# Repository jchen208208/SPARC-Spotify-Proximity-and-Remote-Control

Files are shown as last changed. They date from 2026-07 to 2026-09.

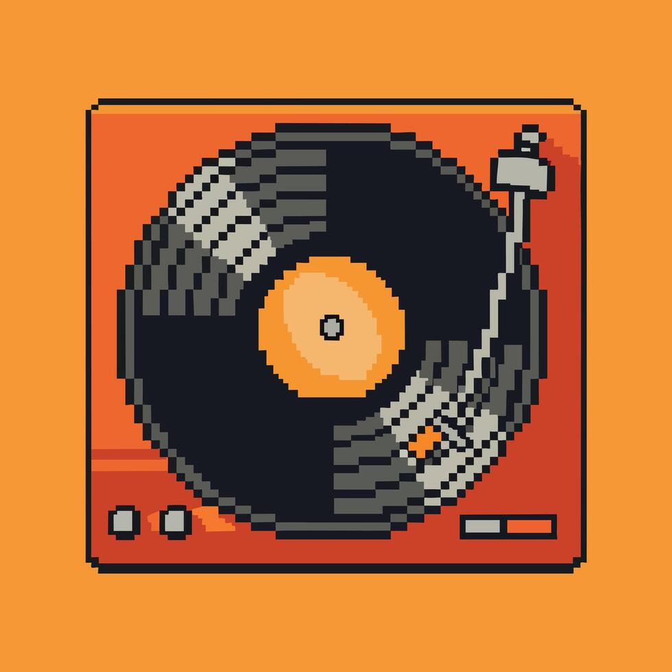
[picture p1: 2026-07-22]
SPARC_assets/record_image.jpg

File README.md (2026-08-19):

# 🎵 SPARC

SPARC

**S**potify **P**roximity **a**nd **R**emote **C**ontrol — a desk-mounted gesture controller.
Wave your hand over it to skip tracks, change volume, or pause. No touchscreen, no buttons,
no phone.

Built for situations where looking at a screen is inconvenient or unsafe — adjusting music
while driving, mainly.

---

## How it works

SPARC pairs to your phone or laptop as a **Bluetooth media remote** — the same class of
device as the play/pause button on a pair of headphones.

It does not talk to Spotify. It sends standard HID media-key presses to the operating
system, which routes them to whatever app is currently playing. That means:

- **No app to install** — pair it in Bluetooth settings and it works
- **No Spotify account, login, or Premium subscription**
- Works on **iOS, Android, macOS, Windows, Linux**
- Works with **any** media app — Spotify, Apple Music, YouTube, podcasts

It also works with the screen off and the phone in your pocket, for the same reason your
headphone buttons do.

---

## Gestures

Two zones above the sensor:

| Zone | Range | Controls |
|---|---|---|
| 1 | 2–15 cm | Tracks |
| 2 | 15–30 cm | Volume |

| Gesture | Zone 1 | Zone 2 |
|---|---|---|
| Single pass | ⏭ Next track | 🔊 Volume up |
| Double pass (within 0.8s) | ⏮ Previous track | 🔉 Volume down |
| Hold (0.3s) | ⏯ Play/pause | ⏹ Stop the volume ramp |

Volume ramps continuously once started. Hold your hand still to stop it.

---

## Hardware

| Component | Notes |
|---|---|
| ESP32 (WROOM-32) | Built-in Bluetooth — no separate radio module |
| VL53L0X | Time-of-flight distance sensor, I²C on SDA 21 / SCL 22 |
| 8× WS2812B | Volume bar, data on GPIO 18 |
| LED | Play/pause flash, GPIO 4 |

Runs off a power bank.

---

## Flashing

Requires the ESP32 board core, plus the `NimBLE-Arduino`, `Adafruit_VL53L0X` and `FastLED`
libraries.

```bash
arduino-cli compile --fqbn esp32:esp32:esp32 --port /dev/cu.usbserial-0001 --upload sketch_esp_hid
```

Then pair "SPARC" from your device's Bluetooth settings. That's the whole setup.

> A BLE device stops advertising while connected. To pair it to something else, disconnect
> — or **forget** it — on the current device first, or it won't be discoverable.

---

## Repo layout

| Path | |
|---|---|
| `sketch_esp_hid/` | **The product.** BLE HID firmware |
| `sketch_esp/` | Older firmware that talks to the desktop app over Bluetooth Serial |
| `Main.py`, `ui.py`, `core.py` | Desktop app — demo only, see below |
| `Wired_version/`, `Uno_version/`, `sketch_nano/` | Earlier hardware revisions, kept for reference |

**The desktop app is a demo artifact, not part of the product.** It shows album art, a queue
wheel and gesture animations, but it needs the Spotify Web API — which is exactly the
limitation the HID firmware exists to escape. It only works with `sketch_esp/` firmware
flashed; the two builds are mutually exclusive.

---

## Project timeline

What we tried, what broke, and what we changed.

| Stage | Problem | Fix |
|---|---|---|
| **Proximity volume** | Mapping hand *distance* to volume was buggy and misread hand position constantly. Roughly a full day lost to it. | Scrapped continuous tracking for discrete swipes — single pass, double pass, hold. |
| **USB tether** | The board had to stay plugged into the laptop, so it wasn't really a remote. | Went wireless. Tried WiFi first, settled on Bluetooth with an HC-05. |
| **HC-05 on macOS** | Pairing and holding a stable serial connection took a lot of troubleshooting. | Worked through the port/pairing issues, then moved to an ESP32 — its built-in radio removed the separate module entirely. |
| **Terminal window** | The packaged executable still opened a terminal on launch. Not a product. | Built a proper macOS `.app` with a status UI and gesture animations. |
| **Spotify API cap** ⚠️ | Spotify cut Development Mode to **5 users** in Feb 2026 and required Premium. Extended quota has been organisations-only since May 2025 — no application path for us. **Hard ceiling on the entire product.** | Stopped using the API. Became a **BLE HID device** instead, so the OS routes the commands. Removed the user cap, the Premium requirement, and the app install in one change — and made iPhone possible for the first time, since iOS never supported the old Bluetooth Serial transport. |

### Along the way

- **Leaked credentials.** Early commits contained Spotify tokens. Moved to `.env`, gitignored, purged from history.
- **Sensor took the whole board down.** On a cold power-up the VL53L0X is still booting when `begin()` runs. Failing silently wedged `setup()`, so Bluetooth never came up and the board looked dead. Now it retries five times and carries on regardless.
- **The on-screen keyboard trap.** Off-the-shelf ESP32 HID libraries declare themselves as keyboards, which makes iOS hide the on-screen keyboard system-wide — you couldn't type in any app while SPARC was connected. Fixed by hand-writing a report descriptor that declares media keys *only*.

---

## What's next

- Solder onto perfboard, ditch the breadboard
- Build a case
- A pairing gesture, so switching between devices doesn't mean digging through Bluetooth settings

---

## License

MIT

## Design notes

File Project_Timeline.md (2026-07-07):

# SPARC — Project Timeline

**SPARC (Spotify Proximity and Remote Control)** is a desk-mounted gesture controller that lets you control Spotify hands-free using an Arduino, an ultrasonic distance sensor, and a Python backend connected to the Spotify Web API.

This document tracks the project from the original idea to the current state: what we built at each stage, the problems we ran into, and how we solved them.

---

## Phase 0 — The Idea (early June 2026)

The idea started about a month before the repo existed: control Spotify with hand gestures in the air — no touchscreen, no buttons, no phone. The long-term vision was a product for situations where looking at a screen is inconvenient or unsafe, like adjusting music while driving.

The idea was pitched to two friends, and the three of us formed the team.

---

## Phase 1 — Software Foundation: Python + Spotify API (June 16–17)

**Commits:** `Initial commit` → `toggle playback`

- Created the GitHub repo, README, and MIT license (June 16).
- Set up the Spotify Developer account, created the app project, and connected to the Spotify Web API using **Spotipy**.
- Wrote the first draft of `Main.py` — the backend script that listens for gesture commands and translates them into Spotify API calls (play/pause, next/previous track, volume).
- Wrote the first Arduino firmware draft (`sketch.ino`) for reading the HC-SR04 ultrasonic sensor.

**Issue — leaked credentials:** Early commits included the Spotify cache/token and hardcoded credentials. We moved all private data (client ID, client secret) into a `.env` file, added it to `.gitignore`, and purged the cached tokens from version control (`used a .env folder for private data`, `security fix`, `Delete .spotify_cache`).

---

## Phase 2 — Hardware Build + First Gesture System (June 17–18)

**Commits:** `Create sketch.ino` → `serial signal rework`

- Built the circuit on a breadboard: Arduino Uno + HC-SR04 ultrasonic sensor + jumper wires.
- Programmed the Arduino to classify hand motions and send gesture labels as plain text over USB Serial to the Python script.

**Original design — proximity-based volume:** Hold your hand in a zone, then move it *closer* to the sensor to decrease volume and *farther away* to increase it.

**Issue — the proximity approach didn't work:** The zone/distance-tracking system was buggy and unreliable — it kept misreading hand position and never behaved the way we wanted. Roughly a full day of commits (`pauses fix`, `pause fix again`, `killed V_start`, multiple `sketch.ino` rewrites) went into trying to stabilize it.

**Solution — pivot to swipe gestures.** We scrapped continuous distance tracking and switched to discrete swipe motions:

- **One swipe** → volume up / next track
- **Two swipes** → volume down / previous track
- **Hold** → stop volume change, or toggle play/pause

The commit `new gesture system that ACTUALLY WORKS` (June 18) marks the turning point. After reprogramming the Arduino and testing, everything worked great. We also added false-trigger filtering (distance cap, consecutive-reading confirmation, gesture cooldown) and tuned the volume step rate (`step: 7%, interval: 0.1s`).

---

## Phase 3 — Polish: Sound Effects + Volume LEDs (June 18)

**Commits:** `mp3 files` → `LED FINAL PULL FROM HERE IF EXPLOSION`

- Added **connected / disconnected sound effects** so the user gets audio feedback when the Python script links up with (or loses) the Arduino and Spotify.
- Added **volume indicator LEDs** to the breadboard that light up to show the current volume percentage inside the Spotify app. Got them fully working the same day.

---

## Phase 4 — Going Wireless (June 18–22)

**Commits:** `WiFi IMPLEMENTATION` → `BLUETOOTH WORKS!`

Up to this point, the Arduino had to be plugged into the laptop by USB cable for serial communication — not exactly a remote control.

- First explored a WiFi approach (`WiFi IMPLEMENTATION`).
- Preserved the working USB version in a `Wired_version/` folder as a stable fallback before making wireless changes.
- Settled on Bluetooth using an **HC-05 module**.

**Issue — Mac ↔ HC-05 connection problems:** Getting macOS to reliably pair and hold a serial connection with the HC-05 took a lot of troubleshooting (`BLUETOOTH WORKS!` followed immediately by `fixing bluetooth issue`). After working through the pairing/port issues, the Bluetooth link became stable.

**Result:** The device now runs fully wireless — the Arduino is powered by a power bank and communicates with the laptop over Bluetooth. We also fixed the LEDs to turn off completely when the program disconnects.

---

## Phase 5 — From Script to App (July 5)

**Commits:** `executable file` → `added gesture corresponding animations in the app ui`

The next barrier to a customer-ready product: you had to open an IDE and manually run the Python script.

1. **First attempt — standalone executable:** Packaged `Main.py` into an executable. Problem: it still opened a terminal window when launched, which isn't a good user experience.
2. **Solution — a proper macOS `.app`:** Built a real application with a UI that shows:
   - Whether the **sensor (Arduino)** is connected
   - Whether **Spotify** is connected
   - When both are connected, a "playing" state with **animations for each gesture action**
3. Added the SPARC logo to the UI and as the dock icon, and fixed remaining security issues.

This is the current state of the project: a wireless, power-bank-powered gesture sensor controlled through a double-clickable desktop app.

---

## Current Challenges

### Scaling / Spotify API limits
Each Spotify Developer app in development mode only supports a small number of allowlisted users (~5 active users). Spinning up more developer accounts per batch of users is not maintainable. Moving past this requires applying for **extended quota access**, but Spotify grants that to established companies with significant monthly active users — which isn't feasible for us right now. This makes the project hard to scale into a full startup at the current moment.

---

## What's Next

- **Ditch the breadboard:** Move to an **Arduino Nano** soldered onto a **perfboard** with all wires and resistors, making the whole device far more compact.
- **Build a displayable case:** Enclose the electronics so it looks like an actual product instead of a sensor attached to wires and a microcontroller.

---

## Timeline at a Glance

| Date | Milestone |
|---|---|
| ~Early June 2026 | Idea conceived and pitched; team of 3 formed |
| June 16 | Repo created; README + MIT license |
| June 17 | Spotify Developer setup, API connected, first `Main.py` and Arduino sketch |
| June 17–18 | Circuit built; proximity-based volume control attempted and abandoned |
| June 18 | Swipe-gesture system working; sound effects + volume LEDs added |
| June 18–19 | Wired version stabilized; wireless work begins |
| June 22 | Bluetooth (HC-05) working after Mac pairing troubleshooting |
| July 5 | Standalone executable → full `.app` with status UI, logo, and gesture animations |
| Next | Solder onto perfboard with Arduino Nano; build product case |

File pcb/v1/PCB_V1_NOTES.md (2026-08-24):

# PCB v1 — known issues and bring-up notes

Findings from bringing up the first SPARC PCB on **2026-08-23**. This board carries a bare
`ESP32-WROOM-32` module instead of a devboard, which is where most of the trouble came from.

**TL;DR:** the board works, but the Reset and BOOT buttons are wired across the power rail
instead of to their signal pins, so they do nothing except short 3.3V to ground. Flashing
requires a jumper wire until v2. See [Flashing v1](#flashing-v1-the-jumper-workaround).

---

## What happened

A teammate flashed this board successfully twice on 2026-08-22, then it stopped working
entirely and never flashed again — on his machine or a different one, with or without
reinstalling the USB driver. The same CP2102 adapter flashed a devboard on a breadboard
without issue, which ruled out the adapter, the cable, and the host.

The cause was in the schematic, not the computers.

### The buttons short the power rail

`SW4` (Reset) and `SW5` (BOOT) are each connected **between +3.3V and GND**, rather than
between their signal pin and GND. Tracing the nets:

```
+3.3V ──┬── R4.2   (R4 = 10k, R4.1 → EN)
        └── SW4.2
                      SW4.1 ── GND        ← SW4 closed = +3.3V shorted to GND

+3.3V ──┬── R5.1   (R5 = 10k, R5.2 → IO0)
        └── SW5.2
                      SW5.1 ── GND        ← SW5 closed = +3.3V shorted to GND
```

The pull-ups themselves are correct — `R4` pulls `EN` high, `R5` pulls `IO0` high. The
mistake is that the buttons landed on the **rail side** of each resistor instead of the
**signal side**. Two consequences:

1. Pressing either button collapses the 3.3V rail instead of pulling its pin low.
2. `EN` and `IO0` have **no path to ground at all**, so `GPIO0` can never be held low —
   which makes download mode unreachable by design.

Correct wiring is `EN ── SW4 ── GND` and `IO0 ── SW5 ── GND`.

### Why it worked twice and then never again

Pressing a button browns out the rail. On release the ESP32 does a power-on reset while
`EN` and `IO0` ramp back up through *identical* 10k pull-ups. If `IO0` happens to still be
below its threshold when `EN` crosses its own, the chip latches into download mode by
accident.

That is a genuine race, sensitive to supply ramp rate, cable, temperature and USB port. It
succeeds occasionally and then never again, and no amount of driver reinstalling touches
it. It matched the reported symptom exactly.

> **Do not press Reset or BOOT on a v1 board.** They only short the rail. Use `Switch1` as
> the reset.

### Other v1 problems found

- **`LDO1` (AP2112K-3.3) enable pin floats.** Pin 3 is unconnected, and the part has no
  internal pull-up on `EN` — it must be driven high. The rail happened to come up on
  2026-08-23, but this is an independent source of "works one day, dead the next."
- **No capacitor on `EN`.** The usual 0.1µF to GND for a clean power-on reset is missing.
- **No I2C pull-ups.** `IO16` and `IO17` connect only the ESP32 to the sensor connector.
  It currently works because most VL53L0X breakouts carry their own and the ESP32's
  internal pull-ups are enabled by default, but those are weak (~45kΩ) and fragile.
- **`CP2102.1 (VCC)` is unconnected.** Not a defect — the board is self-powered from the
  TP4056 — but it means the programmer cannot power the board. `Switch1` must be on and
  the TP4056 must have power before flashing.

---

## Flashing v1: the jumper workaround

Since the BOOT button can't pull `GPIO0` low, do it manually. **No soldering required** —
a jumper wire held by hand is enough.

### The two pads

Both are castellations on the **same edge of the ESP32 module** — the edge facing the
CP2102 connector:

| Pad | Signal | Where |
|---|---|---|
| **25** | `IO0` | The **corner** castellation where the bottom row turns and heads up the side, immediately next to pad 24. Sits level with the CP2102 connector's 4th pad, ~5mm away. |
| **38** | `GND` | The far end of that same edge, ~16mm from pad 25. |

> **Counting trap.** This footprint is **14 / 10 / 14**, not the 15 / 8 / 15 shown in most
> online WROOM-32 pinout diagrams. The bottom row is pads 15–24, so **pad 25 is the first
> pin of the side column, not the second.** Getting this wrong costs a lot of failed
> attempts.

Alternative front-side target, ~3mm apart on larger SMD pads: `R5`'s pad facing away from
`R4` (= `IO0`), and `SW5` pad 1 (= `GND`).

### Steps

1. Power the board: TP4056 powered, `Switch1` **on**. The programmer does not power it.
2. Connect the CP2102 to the 4-pin JST header and to the computer. macOS needs **no
   driver** — it has had a built-in CP2102 driver since Big Sur, and installing the Silicon
   Labs one can conflict with it and break things.
3. Hold a jumper wire between **pad 25 and pad 38**.
4. **While still holding it**, flip `Switch1` off, then on. `GPIO0` is sampled only at the
   instant of reset, so the wire must already be in contact — touching it down afterwards
   does nothing.
5. Hold a second longer, then release. Download mode persists until the next reset, so
   there is no rush to run the command.

### Confirming it worked

Watch the ROM banner at **115200 baud** (the app itself runs at 9600):

| Output | Meaning |
|---|---|
| `boot:0x13 (SPI_FAST_FLASH_BOOT)` | Normal boot — `GPIO0` was high, **try again** |
| `boot:0x3 (DOWNLOAD_BOOT(UART0/...))` | **Download mode reached** |

This is much faster feedback than letting `esptool` time out, and it distinguishes "wrong
pad" from "no contact" from "board is dead."

### Flashing

There is **no auto-reset circuit** (DTR/RTS are not wired to the module), so `esptool` must
be told not to reset:

```bash
ESPTOOL=~/Library/Arduino15/packages/esp32/tools/esptool_py/5.3.1/esptool
BUILD=~/Library/Caches/arduino/sketches/<sketch-hash>

$ESPTOOL --port /dev/cu.usbserial-0001 --before no-reset --after no-reset chip-id

$ESPTOOL --port /dev/cu.usbserial-0001 --before no-reset --after no-reset write-flash \
  0x1000  $BUILD/sketch_esp_hid.ino.bootloader.bin \
  0x8000  $BUILD/sketch_esp_hid.ino.partitions.bin \
  0xe000  $BUILD/boot_app0.bin \
  0x10000 $BUILD/sketch_esp_hid.ino.bin
```

Then **remove the jumper** and flip `Switch1` off/on to run the new firmware. Leaving the
wire on just drops it back into download mode.

### Troubleshooting

| Symptom | Cause |
|---|---|
| No `/dev/cu.usbserial*` at all | Adapter unplugged, or a charge-only USB cable |
| `Failed to connect: No serial data received` | Not in download mode — repeat the jumper sequence |
| Nothing on serial at any baud | No 3.3V (floating LDO enable), or TX/RX swapped |
| Boot log missing but board runs | `GPIO15` low at reset suppresses the ROM log by design |

---

## The I2C swap: unresponsive sensor

After remapping the sketch to the PCB pinout, the sensor still reported:

```
VL53L0X NOT FOUND - check wiring (SDA=16, SCL=17, 3V3, GND)
```

### How it was found

The schematic nets read:

```
U2.27(IO16) ── VL53L0X1.3(SDA)
U2.28(IO17) ── VL53L0X1.4(SCL)
```

A brief detour worth recording: `U2.27` and `U2.28` are **pad numbers, not GPIO numbers**.
Pad 27 carries `IO16` and pad 28 carries `IO17`. The giveaway is that **`GPIO28` does not
exist on the ESP32** — its GPIOs are 0–19, 21–23, 25–27 and 32–39.

So per the schematic, `SDA = IO16` and `SCL = IO17`. But on the physical board the two are
**reversed**: `SCL` is on `IO16` and `SDA` is on `IO17`. Either the connector's pin labels
in the schematic are wrong, or the sensor cable is crossed.

I2C is unforgiving about this — a swapped pair produces no bus acknowledgement at all,
which surfaces as `lox.begin()` failing, indistinguishable from an unplugged sensor.

### The fix

Swapping the two constants in the sketch was enough — no rewiring:

```c
#define I2C_SDA 17          // schematic labels these the other way round;
#define I2C_SCL 16          // the board is actually wired SDA=17, SCL=16
```

After reflashing: `VL53L0X ready`, with live distance readings.

---

## Firmware pin mapping

The PCB and the perfboard use completely different pins, so `sketch_esp_hid.ino` selects
between them with a single `#define` at the top. Comment out `BOARD_PCB_V1` to build for
the perfboard.

| Function | PCB v1 | Perfboard |
|---|---|---|
| VL53L0X SDA | `IO17` | `IO21` |
| VL53L0X SCL | `IO16` | `IO22` |
| NeoPixel DIN | `IO15` (via R6) | `IO18` |
| Status LED | `IO27` (via R7) | `IO4` |

`GPIO18`, `GPIO4`, `GPIO21` and `GPIO22` are unconnected on the PCB.

> `GPIO15` is a strapping pin — if it is low at reset the ROM boot log is suppressed. It
> reads high in practice here, so the NeoPixel on that pin has not caused problems, but it
> is worth remembering when a board appears silent.

---

## PCB v2 change list

The four changes to make, in priority order.

### 1. Rewire both buttons — *critical*

Move each button from the rail side of its pull-up to the signal side. This is the change
that turns flashing from a jumper-wire ordeal into pressing two buttons.

```
current (broken):                    v2 (correct):

+3.3V ─┬─ R4 ─ EN                    +3.3V ─ R4 ─┬─ EN
       └─ SW4 ─ GND                               └─ SW4 ─ GND

+3.3V ─┬─ R5 ─ IO0                   +3.3V ─ R5 ─┬─ IO0
       └─ SW5 ─ GND                               └─ SW5 ─ GND
```

- `SW4` (Reset): `EN` ── `SW4` ── `GND`
- `SW5` (BOOT): `IO0` ── `SW5` ── `GND`

### 2. Tie the LDO enable pin high — *critical*

`LDO1` pin 3 (`EN`) is floating. Connect it to `VIN` (pin 1) for always-on. Without this
the 3.3V rail is unreliable and the board may fail to power up at random.

### 3. Add I2C pull-ups

Add **4.7k to +3.3V** on both `IO16` and `IO17`. Currently there are none; the board only
works because the sensor breakout carries its own.

### 4. Fix the SDA/SCL labels

The `VL53L0X1` connector's `SDA`/`SCL` pin labels do not match how the board is actually
built. Correct the schematic (or the cable) so the two agree, and the firmware can go back
to the intuitive `SDA=16, SCL=17`.

### Also worth doing

- **Add a 0.1µF capacitor from `EN` to GND** for a clean power-on reset.
- **Consider wiring `CP2102` DTR/RTS** to the standard auto-reset transistor pair, which
  would remove the manual button dance entirely.
- **Connect `CP2102.1 (VCC)`** or mark it clearly as no-connect, so it is obvious the
  programmer does not power the board.

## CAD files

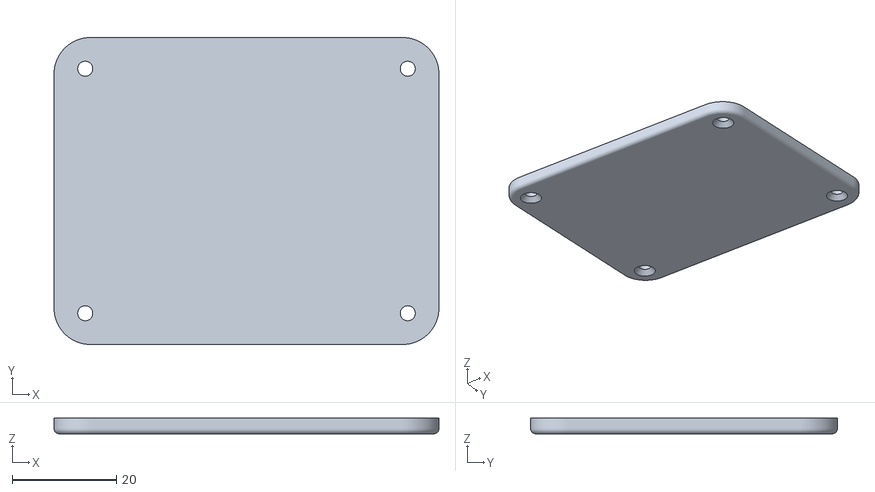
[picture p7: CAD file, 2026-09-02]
enclosure/SPARC_Base.stl
74.0 x 59.0 x 3.00

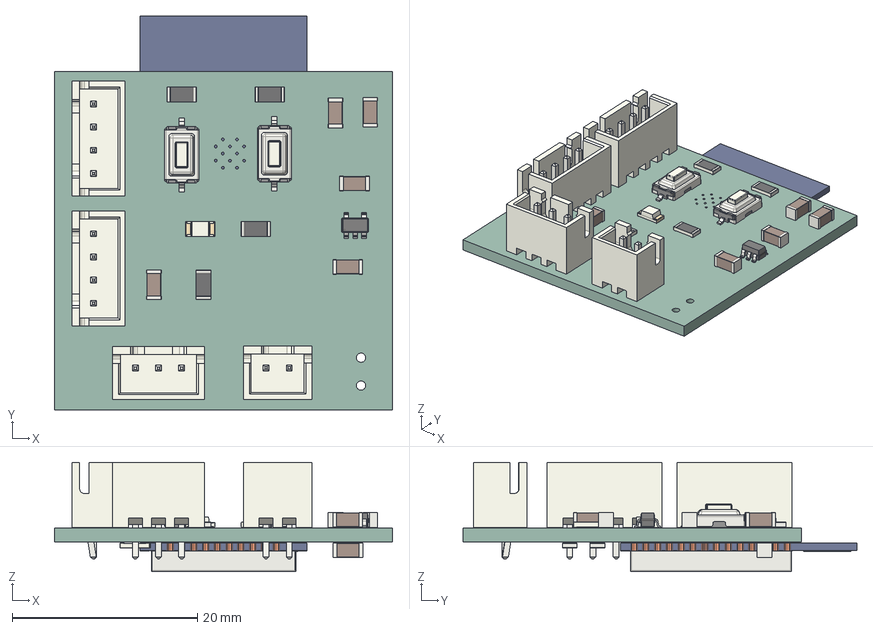
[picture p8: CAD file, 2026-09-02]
pcb/sparc_pcb_v2.step
36.5 x 42.5 x 11.8 mm
C_1206_3216Metric x 6
SOT-23-5
R_1206_3216Metric x 6
JST_B4B_XH_A x 2
PTS636Sx25SMTRLFS x 2
JST_B2B_XH_A
LED_1206_3216Metric
JST_B3B_XH_A
ESP32-WROOM-32
spa7DBF_PCB

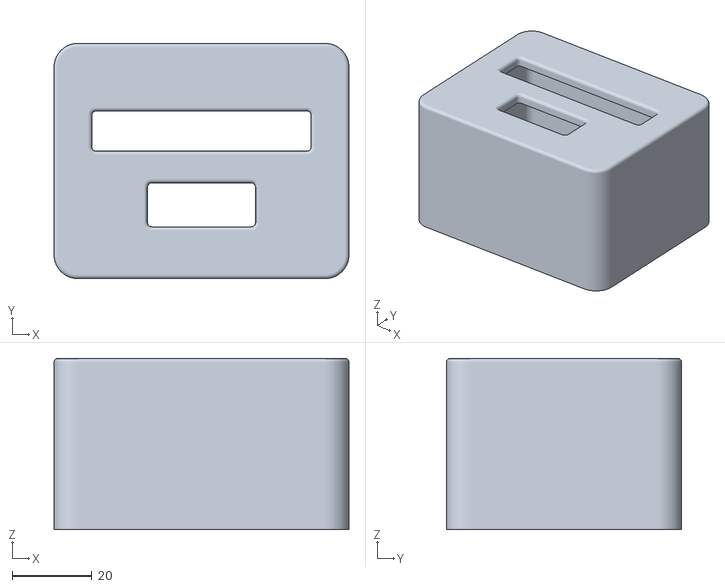
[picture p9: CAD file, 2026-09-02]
enclosure/SPARC_Lid.stl
74.0 x 59.0 x 43.0

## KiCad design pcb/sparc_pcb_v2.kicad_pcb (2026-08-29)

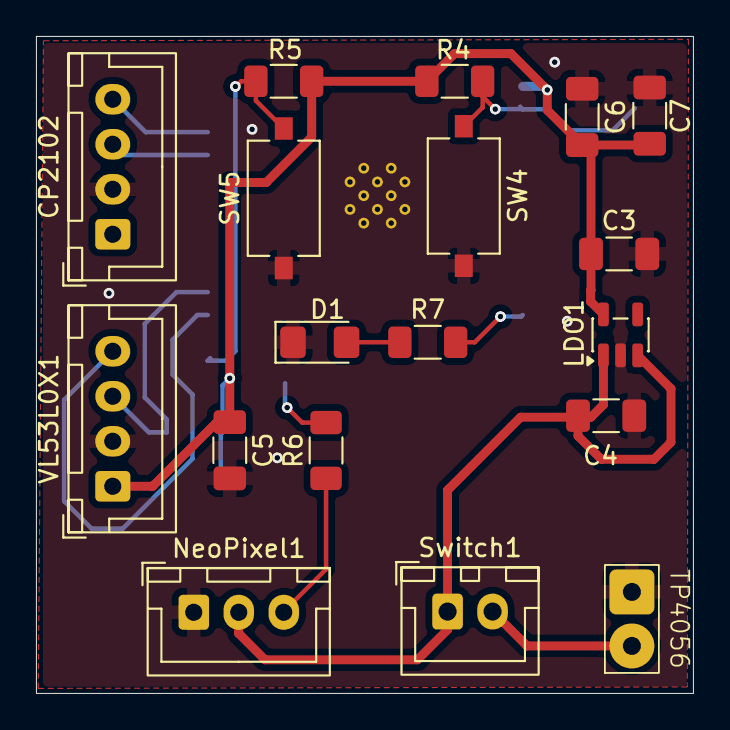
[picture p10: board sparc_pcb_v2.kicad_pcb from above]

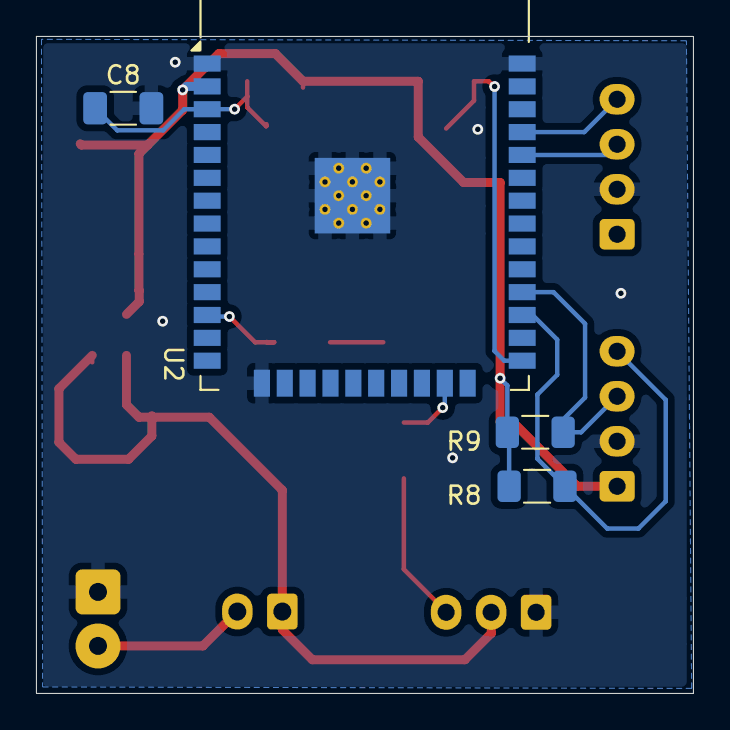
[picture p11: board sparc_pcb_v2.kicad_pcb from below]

Board: 2 copper layers, 36.5 x 36.5 mm, 22 parts (4 on the bottom side), 14 nets.

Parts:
C3, C4, C8: 1µF; C_1206_3216Metric_Pad1.33x1.80mm_HandSolder
C5, C6: 0.1µF; C_1206_3216Metric_Pad1.33x1.80mm_HandSolder
C7: 10µF; C_1206_3216Metric_Pad1.33x1.80mm_HandSolder
CP2102: JST_XH_B4B-XH-A_1x04_P2.50mm_Vertical
D1: LED; LED_1206_3216Metric_Pad1.42x1.75mm_HandSolder
LDO1: AP2112K-3.3; SOT-23-5
NeoPixel1: JST_XH_B3B-XH-A_1x03_P2.50mm_Vertical
R4, R5: 10k; R_1206_3216Metric_Pad1.30x1.75mm_HandSolder
R6, R7: 330; R_1206_3216Metric_Pad1.30x1.75mm_HandSolder
R8, R9: 4.7k; R_1206_3216Metric_Pad1.30x1.75mm_HandSolder
SW4: Reset; SW_Tactile_SPST_NO_Straight_CK_PTS636Sx25SMTRLFS
SW5: BOOT; SW_Tactile_SPST_NO_Straight_CK_PTS636Sx25SMTRLFS
Switch1: JST_XH_B2B-XH-A_1x02_P2.50mm_Vertical
TP4056: TP4056 OUT+_-
U2: ESP32-WROOM-32
VL53L0X1: JST_XH_B4B-XH-A_1x04_P2.50mm_Vertical

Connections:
+3.3V: C3.1, C5.1, C6.2, C7.1, LDO1.5 (VOUT), R4.2, R5.1, R8.1, R9.1, U2.2 (VDD), VL53L0X1.1 (+3V3)
GND: C3.2, C4.2, C5.2, C6.1, C7.2, C8.2, CP2102.2 (GND), D1.1 (K), LDO1.2 (GND), NeoPixel1.1 (GND), SW4.1, SW5.1, TP4056.4 (OUT-), U2.1 (GND), U2.15 (GND), U2.38 (GND), U2.39 (GND), VL53L0X1.2 (GND)
unnamed: CP2102.4 (RXD), U2.35 (TXD0/IO1)
unnamed: CP2102.3 (TXD), U2.34 (RXD0/IO3)
unnamed: D1.2 (A), R7.1
unnamed: NeoPixel1.3 (DIN), R6.1
unnamed: Switch1.2 (B), TP4056.1 (OUT+)
unnamed: C8.1, R4.1, SW4.2, U2.3 (EN)
unnamed: R5.2, SW5.2, U2.25 (IO0)
unnamed: R6.2, U2.23 (IO15)
unnamed: R8.2, U2.27 (IO16), VL53L0X1.4 (SDA)
unnamed: R9.2, U2.28 (IO17), VL53L0X1.3 (SCL)
unnamed: R7.2, U2.12 (IO27)
TP4056 OUT+: C4.1, LDO1.1 (VIN), LDO1.3 (EN), NeoPixel1.2 (+5V), Switch1.1 (A)

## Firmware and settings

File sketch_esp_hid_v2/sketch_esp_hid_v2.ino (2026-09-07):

// SPARC as a BLE HID media remote - no Spotify API, no companion app.
#include <NimBLEDevice.h>
#include <NimBLEHIDDevice.h>

#include <Wire.h>
#include "Adafruit_VL53L0X.h"
Adafruit_VL53L0X lox = Adafruit_VL53L0X();

#include <FastLED.h>

// defines which variables we use
#define BOARD 0  // 2 = PCB v2, 1 = PCB v1, 0 = perfboard

// preprocessor directive
#if BOARD == 2
  #define LED_PIN 15
  #define I2C_SDA 16
  #define I2C_SCL 17
  const int ledPause = 27; // status LED
  #define BATTERY_PIN 0   // TODO: confirm against PCB v2 schematic
#elif BOARD == 1
  #define LED_PIN 15
  #define I2C_SDA 17
  #define I2C_SCL 16
  const int ledPause = 27;
  #define BATTERY_PIN 0   // TODO: confirm against PCB v1 schematic
#else
  #define LED_PIN 18
  #define I2C_SDA 21
  #define I2C_SCL 22
  const int ledPause = 4;
  #define BATTERY_PIN 36   // perfboard - wire divider output here
#endif

#define NUMPIXELS 8

CRGB leds[NUMPIXELS];

// Consumer Control only - deliberately NO keyboard usage page. iOS hides the
// on-screen keyboard system-wide for anything that declares itself a keyboard,
// which would stop the user typing in every app while SPARC is connected.
static const uint8_t REPORT_ID = 1;
static uint8_t reportMap[] = {
  0x05, 0x0C,        // Usage Page (Consumer)
  0x09, 0x01,        // Usage (Consumer Control)
  0xA1, 0x01,        // Collection (Application)
  0x85, REPORT_ID,   //   Report ID (1)
  0x15, 0x00,        //   Logical Minimum (0)
  0x25, 0x01,        //   Logical Maximum (1)
  0x75, 0x01,        //   Report Size (1)
  0x95, 0x07,        //   Report Count (7)
  0x09, 0xB5,        //   Scan Next Track      -> bit 0
  0x09, 0xB6,        //   Scan Previous Track  -> bit 1
  0x09, 0xB7,        //   Stop                 -> bit 2
  0x09, 0xCD,        //   Play/Pause           -> bit 3
  0x09, 0xE2,        //   Mute                 -> bit 4
  0x09, 0xE9,        //   Volume Increment     -> bit 5
  0x09, 0xEA,        //   Volume Decrement     -> bit 6
  0x81, 0x02,        //   Input (Data, Variable, Absolute)
  0x95, 0x01,        //   Report Count (1)
  0x81, 0x03,        //   Input (Constant) - pad to a whole byte
  0xC0               // End Collection
};

const uint8_t KEY_NEXT       = 1 << 0;
const uint8_t KEY_PREV       = 1 << 1;
const uint8_t KEY_PLAY_PAUSE = 1 << 3;
const uint8_t KEY_VOL_UP     = 1 << 5;
const uint8_t KEY_VOL_DOWN   = 1 << 6;

// A zero-length press is ignored by some hosts, so hold the bit briefly.
const unsigned long KEY_HOLD_MS = 15;

NimBLEHIDDevice *hid = nullptr;
NimBLECharacteristic *inputReport = nullptr;
NimBLEServer *pServer = nullptr;
volatile bool bleConnected = false;
volatile bool authDone = false;
volatile uint16_t connHandle = 0;
bool wasConnected = false;
char peerAddr[24] = "";

// Apple Media Service: iOS pushes now-playing state to accessories over GATT - it's
// what Apple Watch uses. Unlike a volume estimate this is a closed loop, since every
// play/pause/seek re-anchors it, so drift can't accumulate. iOS only; on anything
// else discovery just fails and the strip stays in gesture-animation mode.
static const char *AMS_SERVICE       = "89D3502B-0F36-433A-8EF4-C502AD55F8DC";
static const char *AMS_ENTITY_UPDATE = "2F7CABCE-808D-411F-9A0C-BB92BA96C102";

bool amsFound = false;
int amsTries = 0;
unsigned long amsNextTry = 0;

float amsElapsed = 0;    // seconds into the track, as of amsAnchor
float amsRate = 1.0;
float amsDuration = 0;
int amsState = 0;        // 0 paused, 1 playing, 2 rewinding, 3 fast-forwarding
unsigned long amsAnchor = 0;

// Zone boundary in cm. Auto-calibrated: whatever's parked within 1m of the
// sensor for 5+ seconds becomes the "back wall," and the gesture zone runs
// from the sensor out to just short of it.
// Falls back to a fixed 30cm boundary when nothing is sitting in range.
const float DETECT_MIN = 2.0;
const float DEFAULT_ZONE_MAX = 30.0;
float zoneMax = DEFAULT_ZONE_MAX;  // Zone: DETECT_MIN..zoneMax → all gestures

// Calibration tuning
const float CALIBRATION_RANGE = 100.0;          // only consider objects within 1m
const float CALIBRATION_MIN = 10.0;             // ignore stable reads closer than this - more likely a resting hand than a backdrop
const unsigned long CALIBRATION_HOLD_MS = 5000; // must sit still this long to lock in
const float CALIBRATION_TOLERANCE = 3.0;        // cm of wobble still counted as "the same object"
const unsigned long CALIB_LOSS_MS = 1000;       // debounce before reverting to default
const float CALIBRATION_MARGIN = 0.2;           // fraction of the backdrop distance kept clear above the zone

float calibRefDist = -1;
unsigned long calibStableSince = 0;
unsigned long calibNoObjectSince = 0;
bool isCalibrated = false;

// Gesture timing
const unsigned long HOLD_TIME = 300;
const unsigned long DOUBLE_PASS_WINDOW = 800;

// Time, not sample count: the VL53L0X's blocking read paces the loop, so a fixed
// number of samples drifts with the sensor's timing budget.
// Long enough to ride out a dropout mid-wave, short enough that two quick waves are
// still seen as two passes rather than one continuous hold.
const unsigned long OUT_OF_RANGE_MS = 100;

// Non-blocking LED flash
int flashPin = -1;
unsigned long flashStart = 0;
const unsigned long FLASH_DURATION = 150;

bool handInZone = false;
unsigned long handEntryTime = 0;
bool holdFired = false;

int passCount = 0;
unsigned long firstPassExitTime = 0;

// Volume mode: entered by a pass followed immediately by a hold - skip, then
// pause. The distance at that hold becomes a fixed centre point: held farther
// away than VOLUME_DEADZONE_CM from it, the volume ramps up; held nearer than
// that, it ramps down; parked within the dead zone, the ramp pauses. It's
// level-triggered and re-evaluated every loop, so crossing back over centre -
// or reversing direction - takes effect immediately, no separate gesture
// needed. Leaving the zone at any point exits volume mode - there's no
// separate hold-to-exit.
bool volumeMode = false;
bool volumeActive = false;       // a ramp (timed VOL+/VOL- sends) is currently ticking
bool volumeUp = false;           // direction of the current ramp
unsigned long lastVolumeTick = 0;
const unsigned long VOLUME_INTERVAL = 80; // was 200 - faster ramp
float zoneEntryDist = 0;         // distance at zone entry; while in volume mode
                                  // this is the fixed centre ramp direction is
                                  // measured against (set once, never re-baselined)
float lastInZoneDist = 0;        // latest distance reading while still in zone
const float VOLUME_DEADZONE_CM = 2.0; // how far from centre before it starts ramping

// The strip can't show the host's volume - nothing comes back over HID to read, and
// an open-loop estimate desyncs the moment the user touches the volume themselves.
// It confirms gestures instead, which needs no host state and so is never wrong.
enum Anim { ANIM_NONE, ANIM_NEXT, ANIM_PREV, ANIM_PULSE, ANIM_VOL_UP, ANIM_VOL_DN, ANIM_VOL_WAIT };
Anim anim = ANIM_NONE;
unsigned long animStart = 0;
const unsigned long ANIM_STEP = 45;   // ms per LED
const unsigned long PULSE_MS = 320;
const unsigned long FRAME_MS = 20;    // cap redraws; WS2812B writes are not free
unsigned long lastFrame = 0;

// pos 0..1 along the strip, pink at the start → purple at the end. Used for the
// volume-mode "parked" indicator so it reads distinctly from the blue used
// everywhere else (track skips, the ramp comet, the progress bar).
CRGB volWaitColour(float pos) {
  int r = map(pos * 100, 0, 100, 255, 148);
  int g = map(pos * 100, 0, 100,  20,   0);
  int b = map(pos * 100, 0, 100, 147, 211);
  return CRGB(r, g, b);
}

unsigned long outOfRangeSince = 0;

// Debug: periodic Serial dump of raw distance + current zone state.
const unsigned long DEBUG_PRINT_INTERVAL = 200; // ms between prints - 5/sec is readable, doesn't flood
unsigned long lastDebugPrint = 0;

// False if the VL53L0X never came up. Gestures stop working, but Bluetooth keeps
// running so the board still pairs and looks alive, rather than going dark.
bool sensorReady = false;

float readDistanceCm() {
  if (!sensorReady) return -1;             // never poke a sensor that isn't there
  VL53L0X_RangingMeasurementData_t measure;
  lox.rangingTest(&measure, false);
  if (measure.RangeStatus != 0) return -1; // 0 is the only valid status; 1,2,3,5 return garbage
  return measure.RangeMilliMeter / 10.0;   // mm → cm
}

// Watches for something parked within 1m of the sensor. If it holds still long
// enough, that becomes the new outer edge of the gesture zone. A hand gesturing
// through never holds still for the full 5 seconds - its distance keeps
// changing, which restarts the clock below - so normal use can't trigger this,
// only something left sitting in front of the sensor (a monitor stand, a wall,
// a mug).
void updateCalibration(float current) {
  bool objectPresent = (current >= DETECT_MIN && current <= CALIBRATION_RANGE);

  if (!objectPresent) {
    // Nothing within 1m - debounce briefly (a single dropped sample shouldn't
    // undo a calibration), then fall back to the fixed default zone.
    if (calibNoObjectSince == 0) calibNoObjectSince = millis();
    if (isCalibrated && millis() - calibNoObjectSince >= CALIB_LOSS_MS) {
      zoneMax = DEFAULT_ZONE_MAX;
      isCalibrated = false;
      Serial.println("No object within 1m - zone reset to default 30cm");
    }
    calibRefDist = -1;
    calibStableSince = 0;
    return;
  }
  calibNoObjectSince = 0;

  float diff = current - calibRefDist;
  if (diff < 0) diff = -diff;

  if (calibRefDist < 0 || diff > CALIBRATION_TOLERANCE) {
    // First sighting, or it moved enough that this isn't the same dwell - restart the clock.
    calibRefDist = current;
    calibStableSince = millis();
    return;
  }

  calibRefDist = (calibRefDist * 0.9f) + (current * 0.1f); // smooth out sensor jitter

  if (millis() - calibStableSince >= CALIBRATION_HOLD_MS && calibRefDist >= CALIBRATION_MIN) {
    // Stop the gesture range short of the backdrop. Parking zoneMax on the object
    // itself put it right on the inclusive edge of inZone, so sensor jitter around
    // calibRefDist read as a hand entering and leaving the zone with nothing there -
    // spurious gestures. The margin scales with distance because so does the noise.
    // Never less than the wobble we already tolerate as "the same object", or a
    // close backdrop would sit back inside the zone again.
    float margin = calibRefDist * CALIBRATION_MARGIN;
    if (margin < CALIBRATION_TOLERANCE) margin = CALIBRATION_TOLERANCE;
    zoneMax = calibRefDist - margin;
    if (!isCalibrated) {
      isCalibrated = true;
      Serial.print("Zones calibrated to object at ");
      Serial.print(calibRefDist);
      Serial.println("cm");
    }
  }
}

void flashLed(int pin) {
  if (flashPin >= 0) digitalWrite(flashPin, LOW);
  digitalWrite(pin, HIGH);
  flashPin = pin;
  flashStart = millis();
}

void handleFlash() {
  if (flashPin >= 0 && millis() - flashStart >= FLASH_DURATION) {
    digitalWrite(flashPin, LOW);
    flashPin = -1;
  }
}

// pos 0..1 along the strip. SPARC blue: light blue at the start → dark blue at the end.
CRGB barColour(float pos) {
  int r = map(pos * 100, 0, 100, 120,   0);
  int g = map(pos * 100, 0, 100, 200,   0);
  int b = map(pos * 100, 0, 100, 255, 120);
  return CRGB(r, g, b);
}

void stripOff() {
  FastLED.clear();
  FastLED.show();
}

// AMS only pushes on change, so interpolate between updates for a smooth bar.
void renderProgress() {
  if (amsDuration < 1.0) return; // no track loaded yet

  float pos = amsElapsed;
  if (amsState == 1) pos += (millis() - amsAnchor) / 1000.0f * amsRate;
  float frac = constrain(pos / amsDuration, 0.0f, 1.0f);

  float lit = frac * NUMPIXELS;
  int full = (int)lit;
  uint8_t partial = (uint8_t)((lit - full) * 255);

  for (int i = 0; i < NUMPIXELS; i++) {
    leds[i] = barColour((float)i / (NUMPIXELS - 1));
    if (i > full)       leds[i] = CRGB::Black;
    else if (i == full) leds[i].nscale8(partial); // part-lit head keeps 8 pixels smooth
  }
  FastLED.show();
}

void startAnim(Anim a) {
  anim = a;
  animStart = millis();
}

// Non-blocking: called every loop, draws one frame and clears itself when done.
void renderAnim() {
  if (anim == ANIM_NONE) return;
  unsigned long t = millis() - animStart;

  if (anim == ANIM_VOL_WAIT) {
    // Odd and even pixels breathe against each other, one full swap per
    // second - even brightens while odd dims, then reverses. sin() gives a
    // smooth crossfade instead of a hard on/off flicker; the two levels are
    // exact opposites (phase-shifted by PI) so total brightness stays roughly
    // constant as it swaps.
    const unsigned long VOL_WAIT_PERIOD_MS = 1000;
    float phase = (t % VOL_WAIT_PERIOD_MS) / (float)VOL_WAIT_PERIOD_MS; // 0..1
    float evenLevel = (sin(2 * PI * phase) + 1.0f) / 2.0f;              // 0..1
    float oddLevel  = 1.0f - evenLevel;

    for (int i = 0; i < NUMPIXELS; i++) {
      leds[i] = volWaitColour((float)i / (NUMPIXELS - 1));
      float level = (i % 2 == 0) ? evenLevel : oddLevel;
      leds[i].nscale8((uint8_t)(level * 255));
    }
    FastLED.show();
    return; // still non-expiring - just cycles until volumeMode/volumeActive changes
  }

  if (anim == ANIM_PULSE) {
    if (t >= PULSE_MS) { anim = ANIM_NONE; stripOff(); return; }
    uint8_t fade = 255 - (t * 255 / PULSE_MS);
    for (int i = 0; i < NUMPIXELS; i++) {
      leds[i] = barColour((float)i / (NUMPIXELS - 1));
      leds[i].nscale8(fade);
    }
    FastLED.show();
    return;
  }

  unsigned long frame = t / ANIM_STEP;
  bool looping = (anim == ANIM_VOL_UP || anim == ANIM_VOL_DN);
  if (!looping && frame >= NUMPIXELS) { anim = ANIM_NONE; stripOff(); return; }

  int head = frame % NUMPIXELS;
  if (anim == ANIM_PREV || anim == ANIM_VOL_DN) head = NUMPIXELS - 1 - head;

  for (int i = 0; i < NUMPIXELS; i++) {
    int behind = (anim == ANIM_PREV || anim == ANIM_VOL_DN) ? i - head : head - i;
    if (behind >= 0 && behind < 3) {          // lit head plus a short tail
      leds[i] = looping ? volWaitColour((float)i / (NUMPIXELS - 1))
                         : barColour((float)i / (NUMPIXELS - 1));
      leds[i].nscale8(255 >> (behind * 2));
    } else {
      leds[i] = CRGB::Black;
    }
  }
  FastLED.show();
}

// Press and release. Leaving a bit set reads as a stuck key - for volume the
// host would auto-repeat forever.
void sendMediaKey(uint8_t mask, const char *label) {
  if (!bleConnected || inputReport == nullptr) return;

  uint8_t v = mask;
  inputReport->setValue(&v, 1);
  inputReport->notify();
  delay(KEY_HOLD_MS);
  v = 0;
  inputReport->setValue(&v, 1);
  inputReport->notify();

  Serial.print("SENT: ");
  Serial.println(label);
}

// Notification payload: [EntityID][AttributeID][flags][value as UTF-8].
void amsNotify(NimBLERemoteCharacteristic *chr, uint8_t *data, size_t len, bool isNotify) {
  if (len < 3) return;

  char buf[48];
  size_t n = len - 3;
  if (n >= sizeof(buf)) n = sizeof(buf) - 1;
  memcpy(buf, data + 3, n);
  buf[n] = '\0';

  if (data[0] == 0 && data[1] == 1) {        // Player / PlaybackInfo
    // "state,rate,elapsed" - any field may arrive empty, so keep the last known value.
    char *f[3] = {buf, nullptr, nullptr};
    int nf = 1;
    for (char *c = buf; *c && nf < 3; c++) {
      if (*c == ',') { *c = '\0'; f[nf++] = c + 1; }
    }
    if (f[0] && *f[0]) amsState   = atoi(f[0]);
    if (f[1] && *f[1]) amsRate    = atof(f[1]);
    if (f[2] && *f[2]) amsElapsed = atof(f[2]);
    amsAnchor = millis();
  } else if (data[0] == 2 && data[1] == 3) { // Track / Duration
    amsDuration = atof(buf);
  }
}
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
void loop() {
  if (bleConnected && !wasConnected) {
    wasConnected = true;
    Serial.print("BLE connected: ");
    Serial.println(peerAddr);
  } else if (!bleConnected && wasConnected) {
    digitalWrite(ledPause, LOW);
    anim = ANIM_NONE;
    stripOff();
    flashPin = -1;
    resetGestureState();
    handInZone = false;
    outOfRangeSince = 0;
    zoneMax = DEFAULT_ZONE_MAX;
    calibRefDist = -1;
    calibStableSince = 0;
    calibNoObjectSince = 0;
    isCalibrated = false;
    wasConnected = false;
    Serial.println("BLE disconnected");
  }

  float current = readDistanceCm();
  updateCalibration(current);

  if (millis() - lastDebugPrint >= DEBUG_PRINT_INTERVAL) {
    lastDebugPrint = millis();
    Serial.print("dist=");
    if (current < 0) Serial.print("--");
    else Serial.print(current);
    Serial.print("cm  zone=0-");
    Serial.print(zoneMax);
    Serial.print(isCalibrated ? "  [calibrated]" : "  [default]");
    Serial.print(bleConnected ? "" : "  (not connected)");
    Serial.println();
  }

  if (millis() - lastBatteryCheck >= BATTERY_CHECK_INTERVAL) {
    lastBatteryCheck = millis();
    uint8_t pct = readBatteryPercent();
    if (pct != lastBatteryPercent) {
      lastBatteryPercent = pct;
      hid->setBatteryLevel(pct);
      Serial.printf("Battery: %d%%\n", pct);
    }
  }

  if (!bleConnected) return;

  if (volumeActive && millis() - lastVolumeTick >= VOLUME_INTERVAL) {
    lastVolumeTick = millis();
    sendMediaKey(volumeUp ? KEY_VOL_UP : KEY_VOL_DOWN, volumeUp ? "VOL+" : "VOL-");
  }

  // Keep the volume indicator in sync with volumeMode/volumeActive, independent
  // of the gesture state machine below (which only fires startAnim() on the
  // transitions it cares about). Purple while parked and not ramping, comet
  // while ramping, off once volume mode is exited entirely.
  if (volumeMode) {
    if (!volumeActive && anim != ANIM_VOL_WAIT) startAnim(ANIM_VOL_WAIT);
  } else if (anim == ANIM_VOL_UP || anim == ANIM_VOL_DN || anim == ANIM_VOL_WAIT) {
    anim = ANIM_NONE;
    stripOff();
  }

  // A gesture animation always wins for its ~360ms; the bar resumes underneath.
  if (millis() - lastFrame >= FRAME_MS) {
    lastFrame = millis();
    if (anim != ANIM_NONE) renderAnim();
    else if (amsFound)     renderProgress();
  }

  if (authDone && !amsFound && amsTries < 5 && millis() >= amsNextTry) {
    amsTries++;
    amsNextTry = millis() + 2000;
    setupAMS();
  }

  handleFlash();

  bool inZone = (current >= DETECT_MIN && current <= zoneMax);

  if (inZone) outOfRangeSince = 0;
  else if (outOfRangeSince == 0) outOfRangeSince = millis();
  bool handConfirmedGone = (!inZone && outOfRangeSince != 0 &&
                            millis() - outOfRangeSince >= OUT_OF_RANGE_MS);

  if (inZone && !handInZone) {
    handInZone = true;
    handEntryTime = millis();
    holdFired = false;
    zoneEntryDist = current;
    lastInZoneDist = current;
  }

  else if (handConfirmedGone && handInZone) {
    handInZone = false;
    outOfRangeSince = 0;

    if (volumeMode) {
      // Leaving the zone always exits volume mode - swipe or no swipe, ramp
      // running or not. This is the only way out now; there's no hold-to-exit.
      volumeMode = false;
      volumeActive = false;
    } else if (!holdFired) {
      // A dwell that reached HOLD_TIME was a plain play/pause hold, not a
      // pass - only handle it here if the hand left before that.
      if (passCount == 0) {
        passCount = 1;
        firstPassExitTime = millis();
      } else if (passCount == 1 && millis() - firstPassExitTime <= DOUBLE_PASS_WINDOW) {
        sendMediaKey(KEY_PREV, "PREV");
        startAnim(ANIM_PREV);
        passCount = 0;
      } else {
        passCount = 1;
        firstPassExitTime = millis();
      }
    }
  }

  else if (inZone && handInZone) {
    lastInZoneDist = current;

    // In volume mode, ramping is level-triggered off the fixed entry point,
    // not a one-off gesture: above centre by VOLUME_DEADZONE_CM it ramps up,
    // below it ramps down, and inside the dead zone it pauses - re-checked
    // every loop for as long as the hand is held there. startAnim() only
    // fires on a transition (ramp starting or reversing), not every loop,
    // since the animations are looping ones and restarting them each frame
    // would freeze them at frame zero.
    if (volumeMode) {
      float delta = lastInZoneDist - zoneEntryDist;
      bool up   = delta >= VOLUME_DEADZONE_CM;
      bool down = delta <= -VOLUME_DEADZONE_CM;

      if (up || down) {
        bool directionChanged = !volumeActive || (volumeUp != up);
        volumeUp = up;
        volumeActive = true;
        if (directionChanged) {
          lastVolumeTick = 0;
          startAnim(volumeUp ? ANIM_VOL_UP : ANIM_VOL_DN);
        }
      } else {
        volumeActive = false;
      }
    }

    if (!holdFired && millis() - handEntryTime >= HOLD_TIME) {
      holdFired = true;
      // A pass right before this hold is the "skip, then pause" combo that
      // enters volume mode. A hold with nothing preceding it is a plain
      // play/pause instead. (volumeMode is always false by the time a fresh
      // hold can fire here - leaving the zone already cleared it - so there's
      // no "hold while in volume mode" case left to handle.)
      bool comboPending = (passCount == 1 &&
                            millis() - firstPassExitTime <= DOUBLE_PASS_WINDOW);
      resetGestureState();
      if (comboPending) {
        volumeMode = true;
        // Fresh baseline right as the mode starts, so the swipe check above
        // measures movement from here, not from wherever the hand happened
        // to be when it entered the zone for this dwell.
        zoneEntryDist = current;
        lastInZoneDist = current;
      } else {
        sendMediaKey(KEY_PLAY_PAUSE, "PLAY/PAUSE");
        startAnim(ANIM_PULSE);
        flashLed(ledPause);
      }
    }
  }

  if (!handInZone && passCount == 1 && millis() - firstPassExitTime > DOUBLE_PASS_WINDOW) {
    sendMediaKey(KEY_NEXT, "NEXT");
    startAnim(ANIM_NEXT);
    passCount = 0;
  }
}

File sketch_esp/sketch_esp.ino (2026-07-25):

#include "BluetoothSerial.h"
BluetoothSerial btSerial;

#include <Wire.h>
#include "Adafruit_VL53L0X.h"
Adafruit_VL53L0X lox = Adafruit_VL53L0X();

#include <FastLED.h>

#define LED_PIN 18
#define NUMPIXELS 8

CRGB leds[NUMPIXELS];

const int ledPause = 4;

// Zone boundaries in cm
const float DETECT_MIN = 2.0;
const float ZONE1_MAX = 15.0;  // Zone 1: 2-15cm  → track control
const float ZONE2_MAX = 30.0;  // Zone 2: 15-30cm → volume control

// Gesture timing
const unsigned long HOLD_TIME = 300;
const unsigned long DOUBLE_PASS_WINDOW = 800;
const unsigned long READ_INTERVAL = 25;

// 6 consecutive out-of-range readings (150ms) required to confirm hand is gone
const int OUT_OF_RANGE_THRESHOLD = 6;

// Non-blocking LED flash
int flashPin = -1;
unsigned long flashStart = 0;
const unsigned long FLASH_DURATION = 150;

// Heartbeat: Python sends "HB\n" every ~2s; if absent for 5s, go dark
const unsigned long HEARTBEAT_TIMEOUT = 5000;
unsigned long lastHeartbeat = 0;
bool btConnected = false;

bool handInZone = false;
int handZone = 0;
unsigned long handEntryTime = 0;
bool holdFired = false;

int passCount = 0;
int passZone = 0;
unsigned long firstPassExitTime = 0;

// When volume is actively ramping, block all pass gestures
bool volumeActive = false;

int outOfRangeCount = 0;
unsigned long lastReadTime = 0;

// False if the VL53L0X never came up. Gestures stop working, but Bluetooth keeps
// running so the app still connects and says so, rather than the board going dark.
bool sensorReady = false;

float readDistanceCm() {
  if (!sensorReady) return -1;             // never poke a sensor that isn't there
  VL53L0X_RangingMeasurementData_t measure;
  lox.rangingTest(&measure, false);
  if (measure.RangeStatus == 4) return -1; // out of range / invalid
  return measure.RangeMilliMeter / 10.0;   // mm → cm
}

void flashLed(int pin) {
  if (flashPin >= 0) digitalWrite(flashPin, LOW);
  digitalWrite(pin, HIGH);
  flashPin = pin;
  flashStart = millis();
}

void handleFlash() {
  if (flashPin >= 0 && millis() - flashStart >= FLASH_DURATION) {
    digitalWrite(flashPin, LOW);
    flashPin = -1;
  }
}

void updateVolumeLEDs(int vol) {
  int bars = map(vol, 0, 100, 0, NUMPIXELS);
  if (vol > 0 && bars == 0) bars = 1; // any nonzero volume shows at least 1 LED

  for (int i = 0; i < NUMPIXELS; i++) {
    if (i < bars) {
      float pos = (float)i / (NUMPIXELS - 1);

      // SPARC blue: light blue (first LED) → dark blue (last LED)
      int r = map(pos * 100, 0, 100, 120,   0);
      int g = map(pos * 100, 0, 100, 200,   0);
      int b = map(pos * 100, 0, 100, 255, 120);
      leds[i] = CRGB(r, g, b);
    } else {
      leds[i] = CRGB::Black;
    }
  }
  FastLED.show();
}

void resetGestureState() {
  passCount = 0;
  volumeActive = false;
}

void setup() {
  // Serial first: with Serial.begin() after lox.begin(), a sensor that doesn't
  // answer left the board dark with no clue why - Bluetooth was already
  // advertising by then, so it looked alive from the app while loop() never ran.
  Serial.begin(9600);
  Serial.println("SPARC booting");

  btSerial.begin("SPARC");

  Wire.begin(21, 22); // SDA, SCL

  FastLED.addLeds<WS2812B, LED_PIN, GRB>(leds, NUMPIXELS);
  FastLED.setBrightness(10);
  FastLED.clear();
  FastLED.show();

  // On a cold power-up the VL53L0X shares the ESP32's rail and is still booting
  // when we get here, so an immediate begin() finds nothing - and the old sketch
  // ignored the result, wedging setup() so Bluetooth never answered again. An
  // EN-reset or a reflash hid this, because the sensor was already powered by
  // then; that's why it only ever failed on a physical replug. Wait, retry, and
  // carry on either way so a dead sensor can't take Bluetooth down with it.
  delay(200);
  for (int i = 0; i < 5 && !sensorReady; i++) {
    sensorReady = lox.begin();
    if (!sensorReady) delay(200);
  }
  Serial.println(sensorReady
                   ? "VL53L0X ready"
                   : "VL53L0X NOT FOUND - check wiring (SDA=21, SCL=22, 3V3, GND)");

  btConnected = false;

  pinMode(ledPause, OUTPUT);

  Serial.println("setup done");
}

void loop() {
  bool nowConnected = (millis() - lastHeartbeat <= HEARTBEAT_TIMEOUT);
  if (!nowConnected && btConnected) {
    digitalWrite(ledPause, LOW);
    updateVolumeLEDs(0); 
    flashPin = -1;
    resetGestureState();
    handInZone = false;
    outOfRangeCount = 0;
    btConnected = false;
    Serial.println("BT disconnected");
  }

  if (btSerial.available()) {
    String msg = btSerial.readStringUntil('\n');
    msg.trim();
    lastHeartbeat = millis();
    if (!btConnected) {
      btConnected = true;
      Serial.println("BT connected");
    }
    if (msg == "HB") {
    btSerial.println("ACK");
    } else if (msg == "VS") {
      volumeActive = false;
    } else if (msg.startsWith("VOL")) {
      int vol = msg.substring(3).toInt();
      Serial.println(vol);
      updateVolumeLEDs(vol); 
    }
  }

  if (!btConnected) return;

  if (millis() - lastReadTime < READ_INTERVAL) return;
  lastReadTime = millis();

  handleFlash();

  float current = readDistanceCm();
  bool inZone = (current >= DETECT_MIN && current <= ZONE2_MAX);

  if (inZone) {
    outOfRangeCount = 0;
  } else {
    outOfRangeCount++;
  }
  bool handConfirmedGone = (!inZone && outOfRangeCount >= OUT_OF_RANGE_THRESHOLD);

  if (inZone && !handInZone) {
    handInZone = true;
    handEntryTime = millis();
    holdFired = false;
    handZone = (current <= ZONE1_MAX) ? 1 : 2;
  }

  else if (handConfirmedGone && handInZone) {
    handInZone = false;
    outOfRangeCount = 0;

    if (!holdFired && !volumeActive) {
      if (passCount == 0) {
        passCount = 1;
        passZone = handZone;
        firstPassExitTime = millis();
      } else if (passCount == 1 && handZone == passZone && millis() - firstPassExitTime <= DOUBLE_PASS_WINDOW) {
        if (passZone == 1) {
          btSerial.println("S-");
          Serial.println("SENT: S-");
        } else {
          btSerial.println("V-");
          Serial.println("SENT: V-");
          volumeActive = true;
        }
        passCount = 0;
      } else {
        passCount = 1;
        passZone = handZone;
        firstPassExitTime = millis();
      }
    }
  }

  else if (inZone && handInZone) {
    if (!holdFired && millis() - handEntryTime >= HOLD_TIME) {
      btSerial.println("P");
      Serial.println("SENT: P");
      flashLed(ledPause);
      holdFired = true;
      resetGestureState();
    }
  }

  if (!handInZone && passCount == 1 && !volumeActive && millis() - firstPassExitTime > DOUBLE_PASS_WINDOW) {
    if (passZone == 1) {
      btSerial.println("S+");
      Serial.println("SENT: S+");
    } else {
      btSerial.println("V+");
      Serial.println("SENT: V+");
      volumeActive = true;
    }
    passCount = 0;
  }
}

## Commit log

2026-06-18 serial signal rework
    I made it so that let's say the spotify app is at 60% when the user enters volume mode, we calculate the 0% adn 100% distances relative to the current distance, and then we can transfer that onto the slider.
2026-06-19 LED FINAL PULL FROM HERE IF EXPLOSION
    boom
2026-06-19 Made copies for the wired version scripts
2026-06-19 new wired_version folder but with just the changed files
2026-06-19 wired working
2026-06-19 Remove cached Spotify tokens from Wired_version
2026-06-19 LED bug fixed for wired version
    [Main_wired.py, sketch_wired.ino]
2026-06-19 WIRELESS
    wireless
2026-06-22 LED turns off completely when program is disconnected
2026-07-14 new main using id instead of device name
2026-07-16 wheel album cover UI
2026-07-16 horizontal wheel spin
2026-07-17 more compact wheel
2026-07-17 small things
    removed the "SPARC" under the logo in the ui
    replaced the SPARC in the top left with the font of our logo
    cleared the log of previous tracks upon starting the program so it doesnt show incorrect tracts
    [ui.py]
2026-07-17 other carousel fixes
    ngl i dont even remember what i fixed i think the carousel still was guessing the previous track log and i fix that good job jc
    [core.py, ui.py]
2026-07-17 record ring with correct spacing and works if you switch playlists
    [ui.py]
2026-07-19 fixing previous record rendering
    [core.py, ui.py]
2026-07-19 3D box and fixed glitch
    [ui.py]
2026-07-19 repo cleanup: untrack OS junk, drop duplicate uno sketch, fix workflow entry point
    [sketch_uno.ino]
2026-07-20 fixing textrure and refinement
    [ui.py]
2026-07-20 fixed supporting beam kink
    [ui.py]
2026-07-22 keep phonograph ui
    main's ui.py had dropped the phonograph/trumpet art, shuffle discs and
    playlist prevs; keeping this version. core.py and the sketches stay on
    the teammates' led-strip work as pulled.
2026-07-22 restore track_prevs and shuffle in core.py
    The led-strip core.py dropped the context-order machinery, so ui.py's
    shuffle disc and playlist-prevs read keys nothing set. Restores
    _playlist_window and friends, status["shuffle"], and the seed_history
    fallback. No led code touched.
2026-07-22 untrack build artifacts, dedupe uno sketch path
    __pycache__/ was dropped from .gitignore in the merge; re-added and the
    tracked .pyc/.DS_Store files untracked (still on disk). sketch_uno.ino
    was tracked at two paths - kept the sketch_uno/ one the Arduino IDE
    requires, which is the convention the other three sketches follow.
2026-07-25 dimmer leds
2026-07-25 new led colour gradient
    light blue to dark blue
2026-07-27 added gradient glow to current record
2026-08-08 adding all the files for the pcb, schematic and stuff
    [sparc_pcb_v1.kicad_pcb, sparc_pcb_v1.kicad_sch]
2026-08-19 fixing led strip off issue
2026-08-19 gesture animations on the led strip
2026-08-22 flexible zones kinda
    sensors fault
2026-08-24 calibrated zones
    if there's a wall or ceiling within 1m of the sensor's range, the zones will split that in half. else, we fall back on the 15/30cm zones
2026-08-24 sketch with pins for pcb
2026-08-24 fixed pcb schematic
    fixed boot and reset buttons, added EN delay capacitor, fixed floating EN pin for LDO1, added resistor pullups for the 2 busses, and relabeled SCL and SDA
    [sparc_pcb_v2.kicad_pcb, sparc_pcb_v2.kicad_sch]
2026-08-24 placing C8, R8, and R9
    [sparc_pcb_v2.kicad_pcb]
2026-08-24 fixed sw4 and sw5 wiring on the pcb
    [sparc_pcb_v2.kicad_pcb]
2026-08-24 new I2C tracing and pull-up resistors
    [sparc_pcb_v2.kicad_pcb]
2026-08-24 v2 pcb complete, everything should be working
    [sparc_pcb_v2.kicad_pcb]
2026-08-24 gerber file
    [sparc_pcb_v2-B_Courtyard.gbr, sparc_pcb_v2-B_Cu.gbl, sparc_pcb_v2-B_Fab.gbr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]
2026-08-24 uploadable gerber zip to fabs
    [sparc_pcb_v2-B_Courtyard.gbr, sparc_pcb_v2-B_Cu.gbl, sparc_pcb_v2-B_Fab.gbr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]
2026-08-25 active pcb layers
2026-08-29 cleaned up the pcb a bit and made it pass drc
    [sparc_pcb_v2.kicad_pcb]
2026-08-30 prevents lag behinds on the progress bar if given a partial PlaybackInfo update
    [sketch_esp_hid_v2.ino]
2026-08-30 changed entry logic
    got rid of min and max readings and switched as timer system for distinguishing between play/pause and entering volume mode
2026-08-30 send a volume signal once every 100ms )
    so that one loop() iteration doesn't handle too many volume calls (since each sendMediaKey has a 15ms delay
    [sketch_esp_hid_v2.ino]
2026-08-31 made it so that calibration only runs when no hand is being tracked
2026-09-02 enclosure case stl files
    [SPARC_Base.stl, SPARC_Lid.stl, sparc_pcb_v2.step]
2026-09-07 purple leds for volume and no more three pass
    pass + hold = volume mode
    purple leds to signify volume mode
2026-09-07 purpled led for ramping volume
    purple led for ramping volume
2026-09-07 send battery reading but idk the pin
    what is the pin help
